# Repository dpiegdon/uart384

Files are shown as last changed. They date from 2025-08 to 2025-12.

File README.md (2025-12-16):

<!-- vim: tw=72 fo+=a
-->

UART384 - FPGA devboard & USB-stick
===================================

<div>
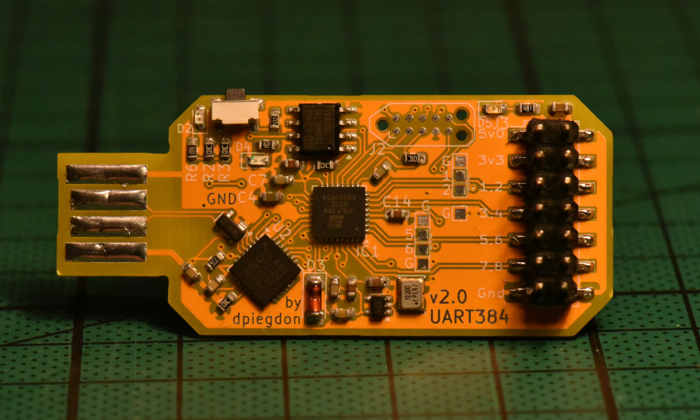
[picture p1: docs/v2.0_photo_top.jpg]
PCB-v2.0 Photo Top
    
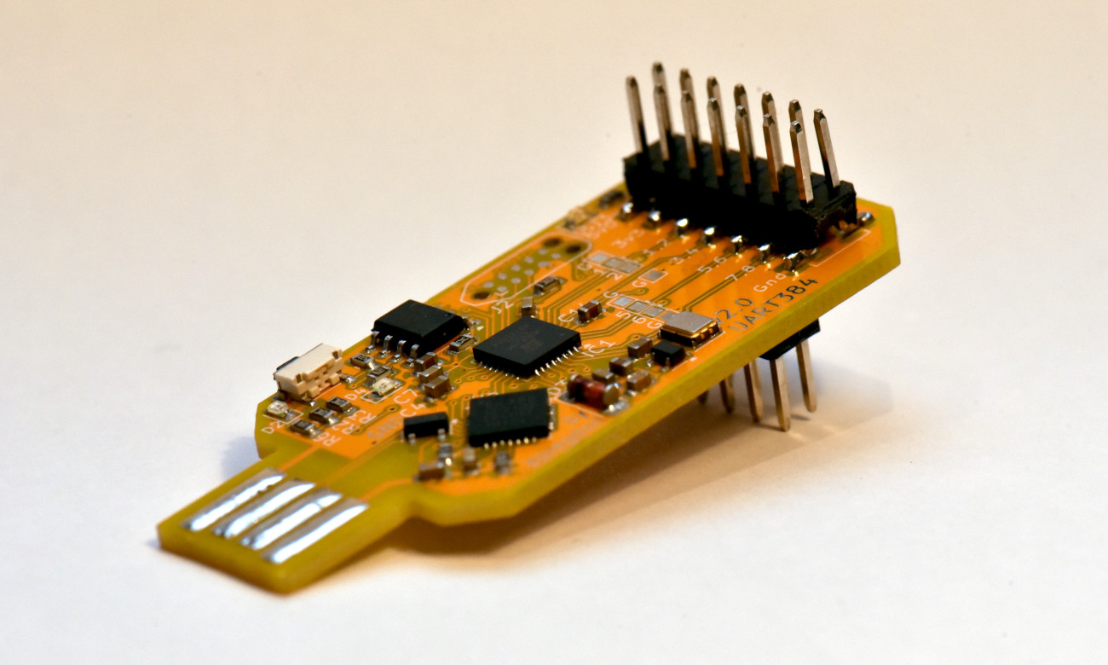
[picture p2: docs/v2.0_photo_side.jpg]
PCB-v2.0 Photo Side
    
</div>

<div>
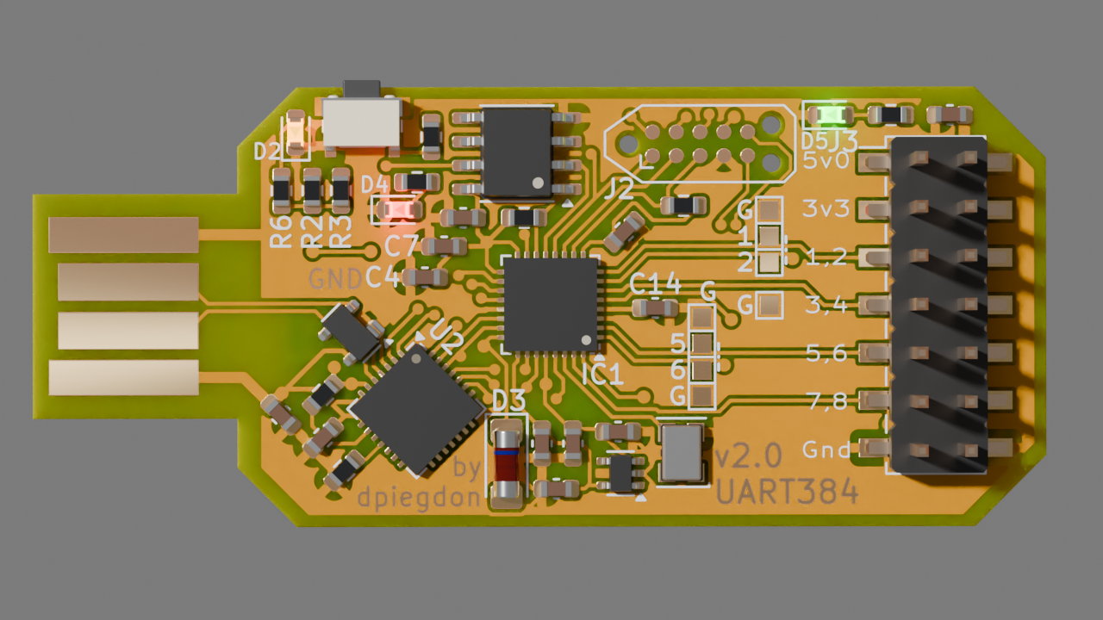
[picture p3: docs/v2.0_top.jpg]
	
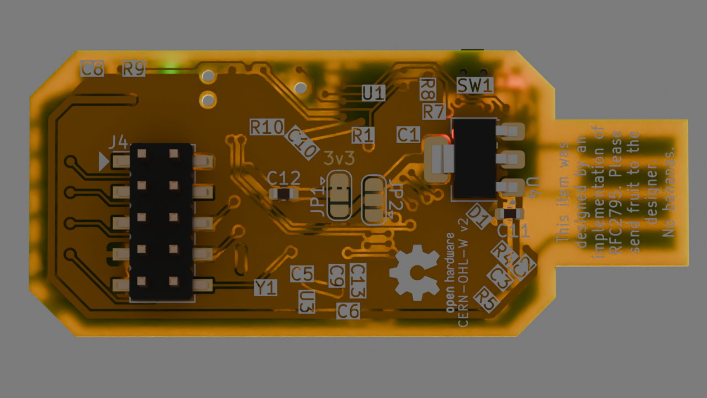
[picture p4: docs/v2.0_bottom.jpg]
	
</div>

This is a mini-devboard for the Lattice iCE40LP384, the *BEST* 🔍 FPGA
ever!

Features:
- USB-stick form-factor
- USB is connected to Silabs CP2102 USB-to-UART bridge
- Tiny Lattice iCE40LP384 with connections:
  - 384 LUTs/FFs
  - UART
  - 2 LEDs
  - 1 push-button
  - 8 GPIOs on pinheader
  - 32MHz oscillator
- small flash for bitstream
- TC2050 connector (bottom side) for programming the flash

NOTE: device is not programmable via USB

Gateware
========

"Why?", you ask?

Mostly for fun and training; there are a few gateware options available in this repository:

Entropy generator
-----------------

`gateware/entropy_generator.v`

High quality entropy source using metastability from ringoscillators fed
into the spongent hash algorithm. 

This is one of the original reasons this board was created for: I wanted
a USB stick that generates cryptographically sound entropy that can be
used to enhance system entropy on linux.

`gateware/tools/seedrng.py` can be used to receive the entropy and
inject it directly into the kernel entropy pool.

SPI and GPIO over UART tunnel
-----------------------------

`gateware/relay_spi.v`

This variant allows complex muxing of SPI lines from an SPI master core
to all GPIO1..8 pins, as well as the internal program flash. All these
pins can also be muxed as GPIO input or output and controlled/sampled.
All that via a simple UART protocol.

This gives full control of inputs and outputs, as well as efficient SPI
communication via SPI core, in any configuration. The SPI core is used
for SPI transfer by pulling RTS down, then CS is automatically pulled
down and data is seemlessly interchanged between SPI and UART.

This e.g. allows reprogramming the internal flash, or external SPI
devices, including Lattice iCE40 FPGAs if GPIOs are used to trigger
their CRESET. Since CDONE can also be sampled, this also allows
programming any iCE40 FPGA in slave mode, fully replacing any other
needed programming board to flash/program a Lattice iCE40 FPGA. Note
that the FPGA is pretty much full, no further features will be added to
this gateware.

See `gateware/tools/spi_device.py` for general SPI command abstraction,
and `gateware/tools/flashtool.py` and `gateware/tools/spi_device.py` as
an example client to work with the onboard (or any other) serial flash.

Ring oscillator entropy generator
---------------------------------

`gateware/ring_noise.v`

Low quality entropy generator using metastability from ringoscillators
fed into a linear feedback shift register.

UART pass-through
-----------------

`gateware/uart_passthrough.v`

A simple example that only passes UART signals along to the GPIO header
and shows changes on RX/TX lines on the LEDs (with some timeout).

Variable delay ring oscillator
------------------------------

`gateware/variable_ringoscillator.v`

Experiments with a ringoscillator with a reconfigurable delay-line.
Delay can be changed at runtime via UART.

License
=======

The hardware (Schematic, PCB) is licensed under CERN-OHL-W v2.
See `cern_ohl_w_v2.txt`.

The software is licensed under LGPL v2.0, unless specified otherwise
in a subrepository. See `LGPLv2.0.txt`.

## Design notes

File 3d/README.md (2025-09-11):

Tested with FreeCAD 1.0.2 and Blender 4.5.2 LTS:

FreeCAD workflow
================

Direct export of 3d STEP file
-----------------------------

In KiCad PCB Editor: File -> Export -> Step, then enable everything on the left:

- Board body
- cut vias in board body
- export silkscreen
- export solder mask
- export *all* components
- export tracks and vias
- export pads
- export zones
- export inner conductor layers
- fuse shapes
- fill all vias
- optionally on the right: ignore DNP components
- Export, saving as STEP file

In FreeCAD: import STEP file via File -> Import.

=> Now create enclosure (or whatever else) in CAD.

Old version
-----------

NOTE: this does not work well when exporting to blender at a later stage. Better use the direct 3d export above.

In KiCad PCB Editor:

- Plot silkscreen layers to DXF format:
  - File -> Plot
  - Set Plot format to DXF,
  - Select Silkscreen layers (don't care about others)
  - Plot

In FreeCAD: Use KiCadStepUp bench to:
- load board
- add tracks
- add silkscreen (exported DXF file)

Blender workflow
================

Export Enclosure and PCB
------------------------

In FreeCAD: select PCB and enclosure bodies, then: File -> Export, then export as glTF.

Import in Blender
-----------------

Import glTF file via: File -> Import.

Knock yourself out!

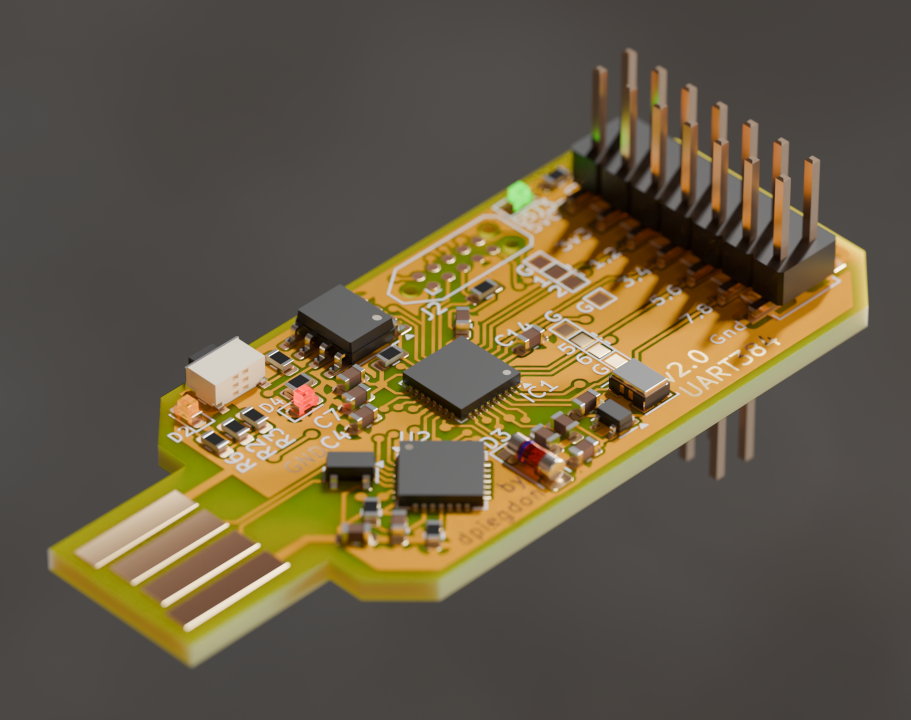
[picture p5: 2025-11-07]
docs/v2.0_side.jpg

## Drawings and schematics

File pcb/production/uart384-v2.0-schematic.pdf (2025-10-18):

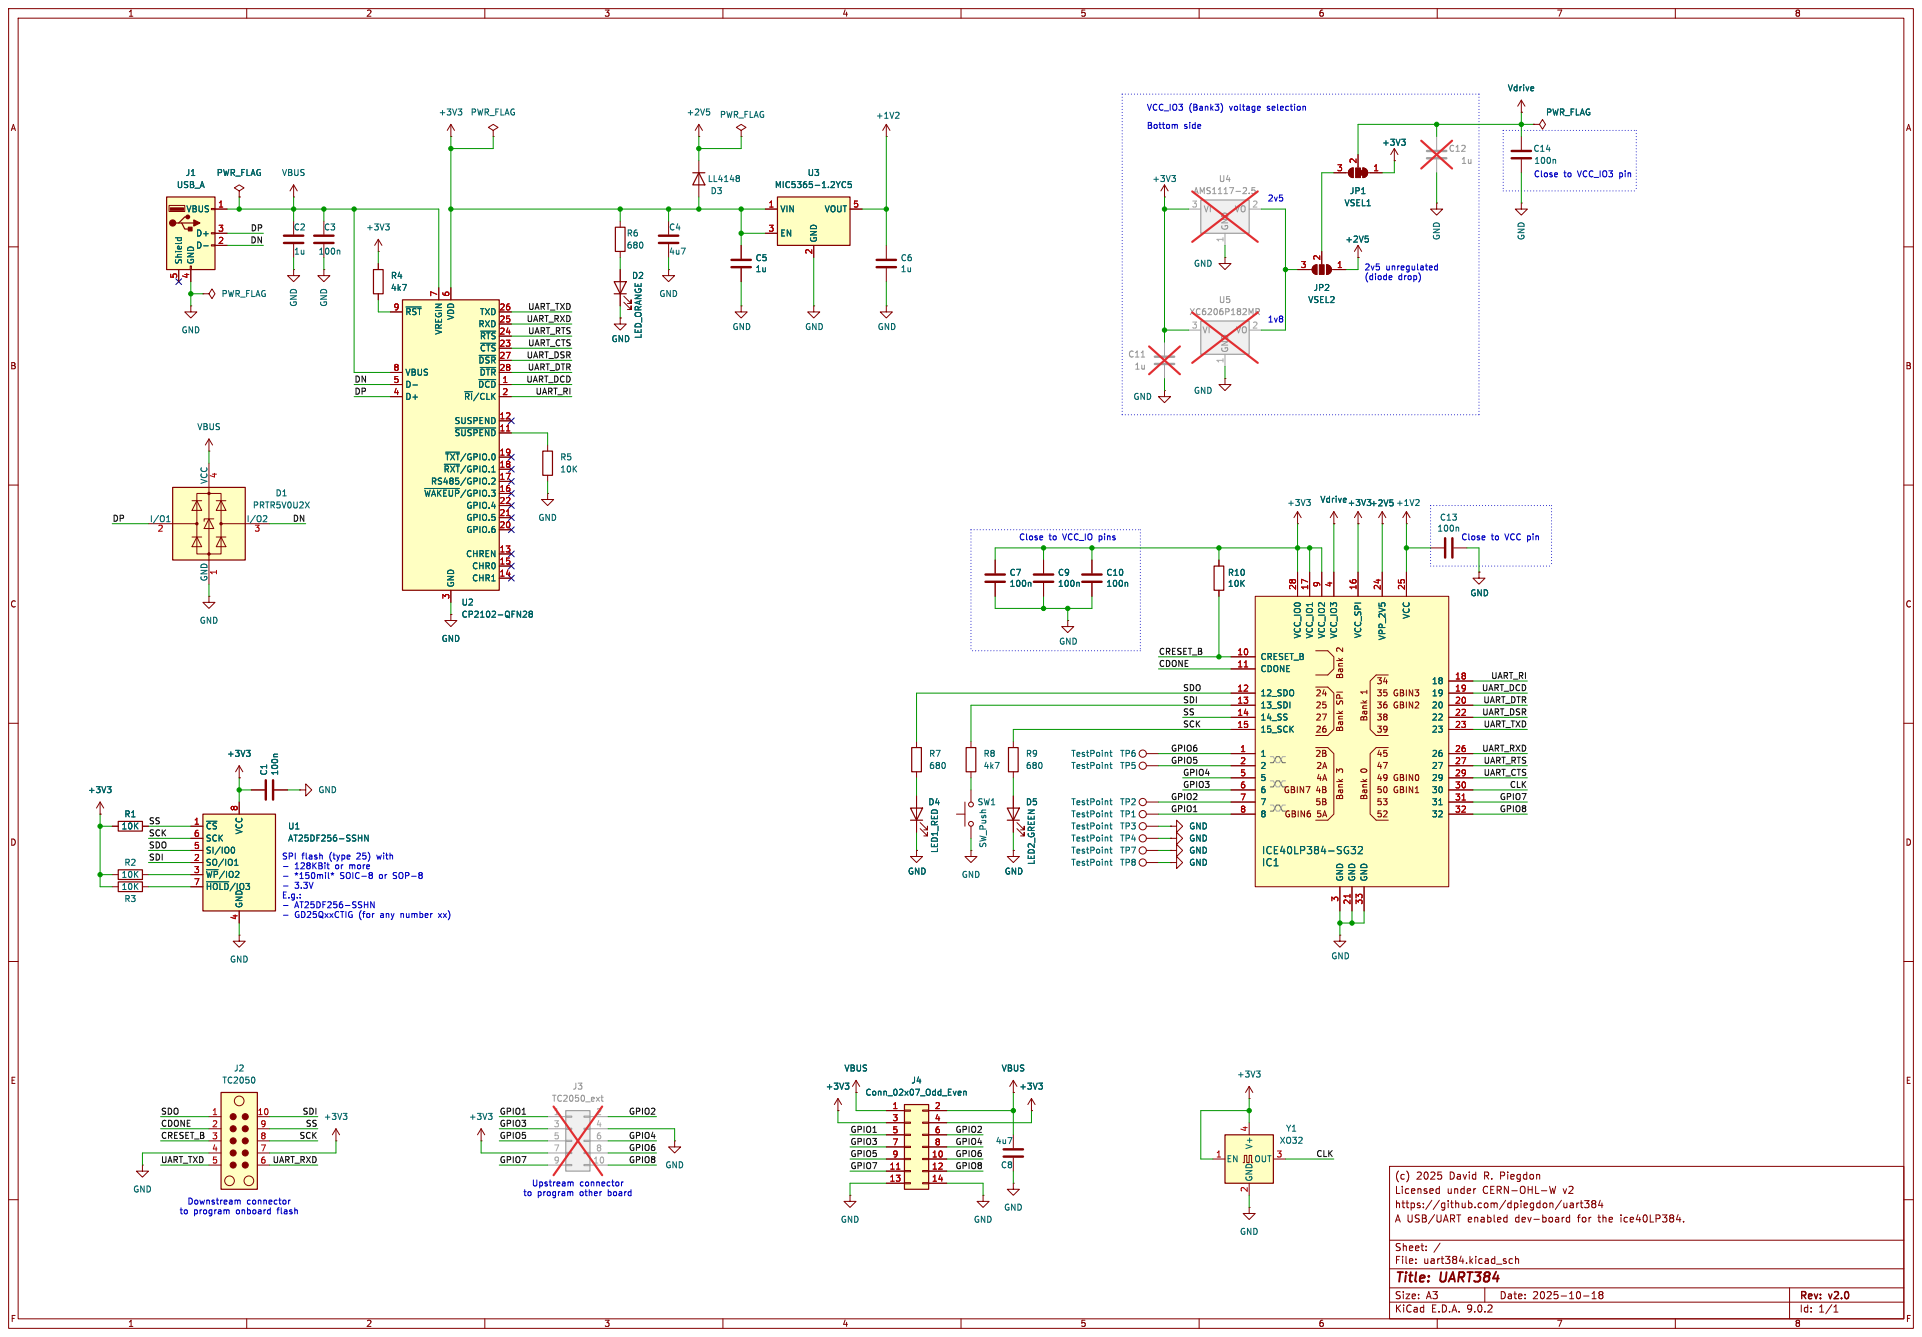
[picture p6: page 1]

(diode drop) 2v5 VCC_IO3 (Bank3) voltage selection Close to VCC_IO pins SPI flash (type 25) with

3 TXD 26 RXD 25 ~{RTS} 24 ~{CTS} 23 ~{DSR} 27 ~{DTR} 28 ~{DCD}1 ~{RI}/CLK2 SUSPEND 12 ~{SUSPEND}11 ~{TXT}/GPIO.019 ~{RXT}/GPIO.118 RS485/GPIO.2 17 ~{WAKEUP}/GPIO.316 GPIO.4 22 GPIO.5 21 GPIO.6 20 CHREN 13 CHR0 15 CHR1 14 U2 CP2102-QFN28 R4

3 TXD 26 RXD 25 ~{RTS} 24 ~{CTS} 23 ~{DSR} 27 ~{DTR} 28 ~{DCD}1 ~{RI}/CLK2 SUSPEND 12 ~{SUSPEND}11 ~{TXT}/GPIO.019 ~{RXT}/GPIO.118 RS485/GPIO.2 17 ~{WAKEUP}/GPIO.316 GPIO.4 22 GPIO.5 21 GPIO.6 20 CHREN 13 CHR0 15 CHR1 14 R4

- GD25QxxCTIG (for any number xx)

to program onboard flash

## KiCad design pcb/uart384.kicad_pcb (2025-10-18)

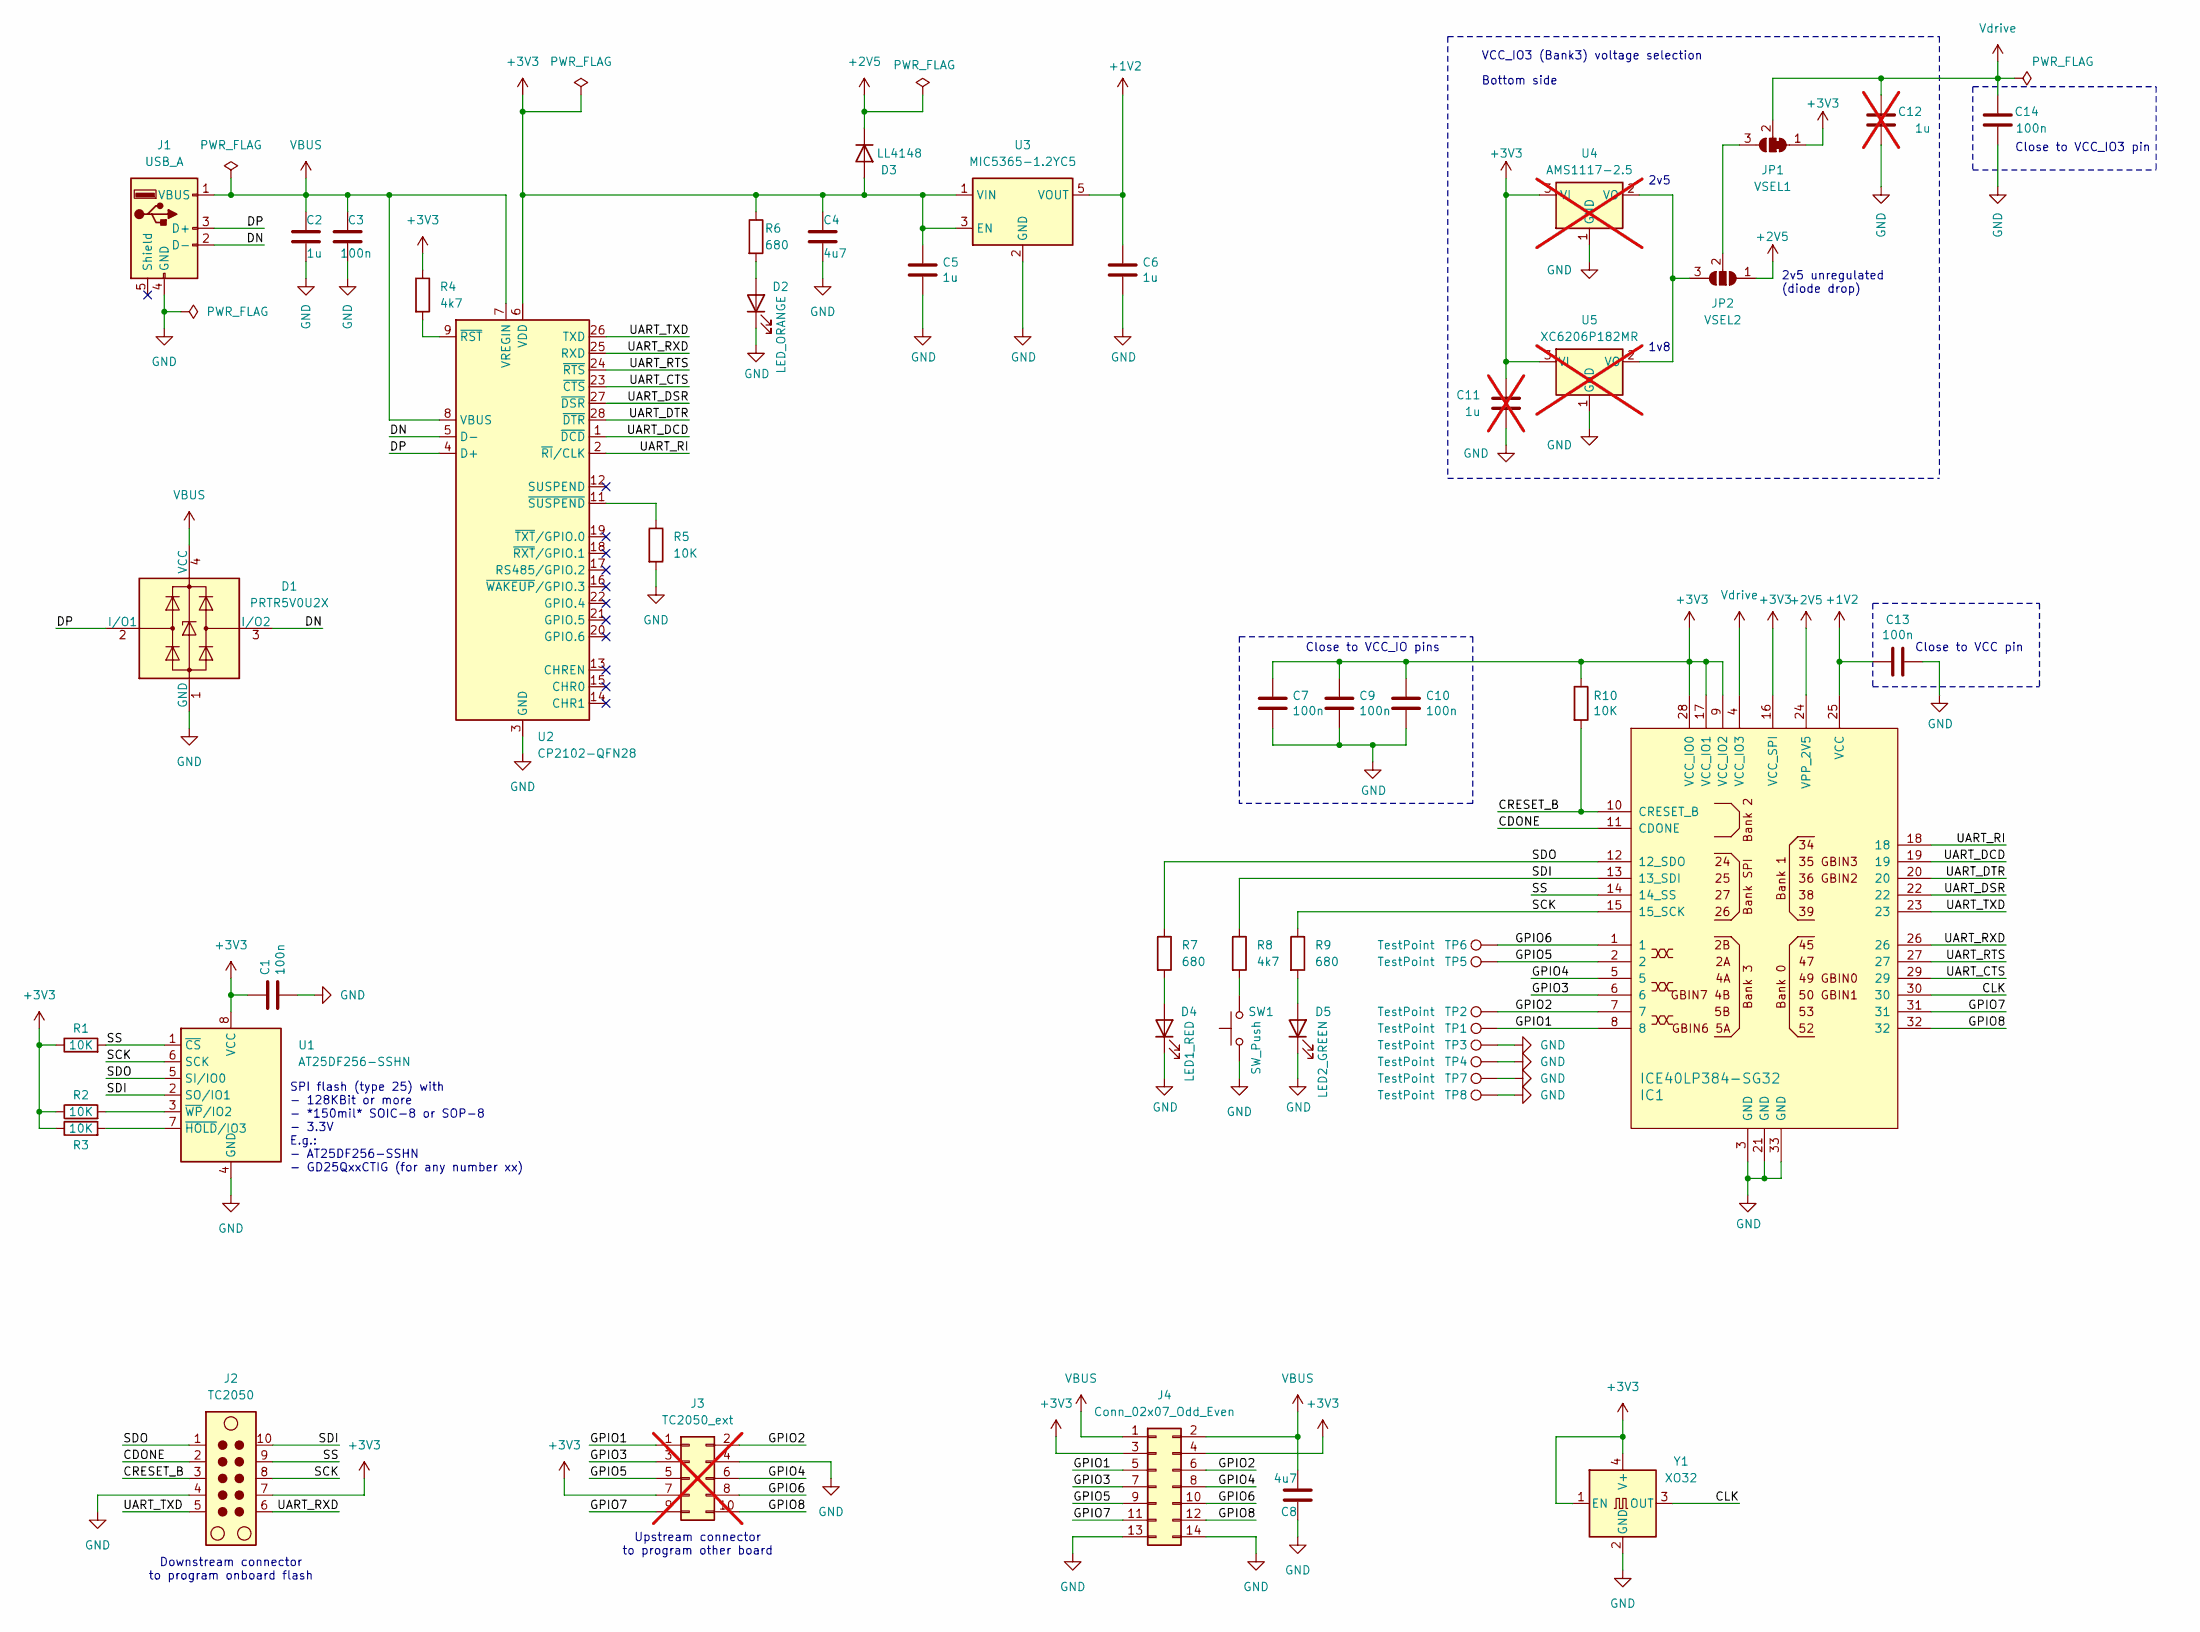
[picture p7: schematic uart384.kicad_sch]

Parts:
C1, C3, C7, C9, C10, C13, C14: 100n; C_0603_1608Metric
C2, C5, C6: 1u; C_0603_1608Metric
C4, C8: 4u7; C_0603_1608Metric
C11, C12: 1u; C_0603_1608Metric; not fitted
D1: PRTR5V0U2X; SOT-143
D2: LED_ORANGE; LED_0603_1608Metric
D3: LL4148; D_MiniMELF
D4: LED1_RED; LED_0603_1608Metric
D5: LED2_GREEN; LED_0603_1608Metric
IC1: ICE40LP384-SG32; QFN-32-1EP_5x5mm_P0.5mm_EP3.6x3.6mm
J1: USB_A; CONN-USB-A-PCB-TRACES
J2: TC2050; Tag-Connect_TC2050-IDC-NL_2x05_P1.27mm_Vertical
J3: TC2050_ext; PinHeader_2x05_P2.54mm_Vertical_SMD; not fitted
J4: Conn_02x07_Odd_Even; PinHeader_2x07_P2.54mm_Vertical_SMD
JP1: VSEL1; SolderJumper-3_P1.3mm_Bridged2Bar12_RoundedPad1.0x1.5mm
JP2: VSEL2; SolderJumper-3_P1.3mm_Open_RoundedPad1.0x1.5mm
R1, R2, R3, R5, R10: 10K; R_0603_1608Metric
R4, R8: 4k7; R_0603_1608Metric
R6, R7, R9: 680; R_0603_1608Metric
SW1: SW_Push; TS-1224W_Side_Button_2x4x3.3mm_3.5mm_3.8mm_SMD_Aliexpress
TP1, TP2, TP3, TP4, TP5, TP6, TP7, TP8: TestPoint; TestPoint_Pad_1.0x1.0mm
U1: AT25DF256-SSHN; SOIC-8_3.9x4.9mm_P1.27mm
U2: CP2102-QFN28; QFN-28-1EP_5x5mm_P0.5mm_EP3.35x3.35mm
U3: MIC5365-1.2YC5; SOT-353_SC-70-5
U4: AMS1117-2.5; SOT-223-3_TabPin2; not fitted
U5: XC6206P182MR; SOT-23-3; not fitted
Y1: XO32; Oscillator_SMD_EuroQuartz_XO32-4Pin_3.2x2.5mm

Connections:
+1V2: C6.1, C13.2, IC1.25 (VCC), U3.5 (VOUT)
+2V5: D3.1 (K), IC1.24 (VPP_2V5), JP2.1 (A)
+3V3: C1.1, C4.1, C5.1, C7.1, C9.1, C10.1, C11.2, D3.2 (A), IC1.9 (VCC_IO2), IC1.16 (VCC_SPI), IC1.17 (VCC_IO1), IC1.28 (VCC_IO0), J2.7, J3.7, J4.3, J4.4, JP1.1 (A), R1.1, R2.1, R3.1, R4.1, R6.1, R10.1, U1.8 (VCC), U2.6 (VDD), U3.1 (VIN), U3.3 (EN), U4.3 (VI), U5.3 (VI), Y1.1 (EN), Y1.4 (V+)
/CDONE: IC1.11 (CDONE), J2.2
/CLK: IC1.30, Y1.3 (OUT)
/CRESET_B: IC1.10 (CRESET_B), J2.3, R10.2
/DN: D1.3 (I/O2), J1.2 (D-), U2.5 (D-)
/DP: D1.2 (I/O1), J1.3 (D+), U2.4 (D+)
/GPIO1: IC1.8, J3.1, J4.5, TP1.1
/GPIO2: IC1.7, J3.2, J4.6, TP2.1
/GPIO3: IC1.6, J3.3, J4.7
/GPIO4: IC1.5, J3.6, J4.8
/GPIO5: IC1.2, J3.5, J4.9, TP5.1
/GPIO6: IC1.1, J3.8, J4.10, TP6.1
/GPIO7: IC1.31, J3.9, J4.11
/GPIO8: IC1.32, J3.10, J4.12
/SCK: IC1.15 (15_SCK), J2.8, R9.1, U1.6 (SCK)
/SDI: IC1.13 (13_SDI), J2.10, R8.1, U1.2 (SO/IO1)
/SDO: IC1.12 (12_SDO), J2.1, R7.1, U1.5 (SI/IO0)
/SS: IC1.14 (14_SS), J2.9, R1.2, U1.1 (~CS)
/UART_CTS: IC1.29, U2.23 (~CTS)
/UART_DCD: IC1.19, U2.1 (~DCD)
/UART_DSR: IC1.22, U2.27 (~DSR)
/UART_DTR: IC1.20, U2.28 (~DTR)
/UART_RI: IC1.18, U2.2 (~RI/CLK)
/UART_RTS: IC1.27, U2.24 (~RTS)
/UART_RXD: IC1.26, J2.6, U2.25 (RXD)
/UART_TXD: IC1.23, J2.5, U2.26 (TXD)
GND: C1.2, C2.2, C3.2, C4.2, C5.2, C6.2, C7.2, C8.1, C9.2, C10.2, C11.1, C12.1, C13.1, C14.1, D1.1 (GND), D2.1 (K), D4.1 (K), D5.1 (K), IC1.3 (GND), IC1.21 (GND), IC1.33 (GND), J1.4 (GND), J2.4, J3.4, J4.13, J4.14, R5.2, SW1.1, TP3.1, TP4.1, TP7.1, TP8.1, U1.4 (GND), U2.3 (GND), U2.29 (GND), U3.2 (GND), U4.1 (GND), U5.1 (GND), Y1.2 (GND)
unnamed: D2.2 (A), R6.2
unnamed: D4.2 (A), R7.2
unnamed: D5.2 (A), R9.2
unnamed: JP1.3 (B), JP2.2 (C)
unnamed: JP2.3 (B), U4.2 (VO), U5.2 (VO)
unnamed: R8.2, SW1.2
unnamed: R3.2, U1.7 (~HOLD/IO3)
unnamed: R2.2, U1.3 (~WP/IO2)
unnamed: R4.2, U2.9 (~RST)
unnamed: R5.1, U2.11 (~SUSPEND)
VBUS: C2.1, C3.1, C8.2, D1.4 (VCC), J1.1 (VBUS), J4.1, J4.2, U2.7 (VREGIN), U2.8 (VBUS)
Vdrive: C12.2, C14.2, IC1.4 (VCC_IO3), JP1.2 (C)

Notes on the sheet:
Upstream connector to program other board
VCC_IO3 (Bank3) voltage selection
2v5 unregulated (diode drop)
SPI flash (type 25) with - 128KBit or more - *150mil* SOIC-8 or SOP-8 - 3.3V E.g.: - AT25DF256-SSHN - GD25QxxCTIG (for any number xx)
Bottom side
2v5
1v8
Close to VCC pin
Downstream connector to program onboard flash
Close to VCC_IO pins
Close to VCC_IO3 pin

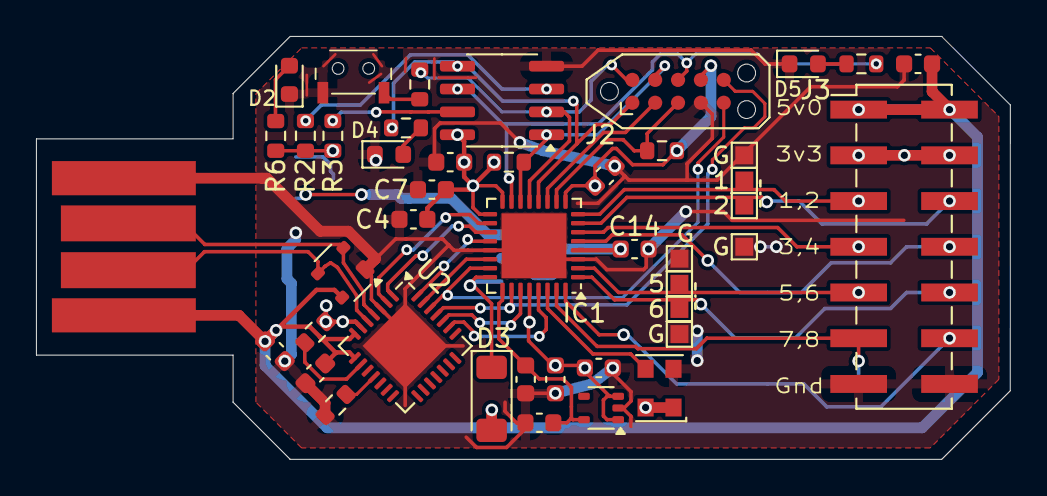
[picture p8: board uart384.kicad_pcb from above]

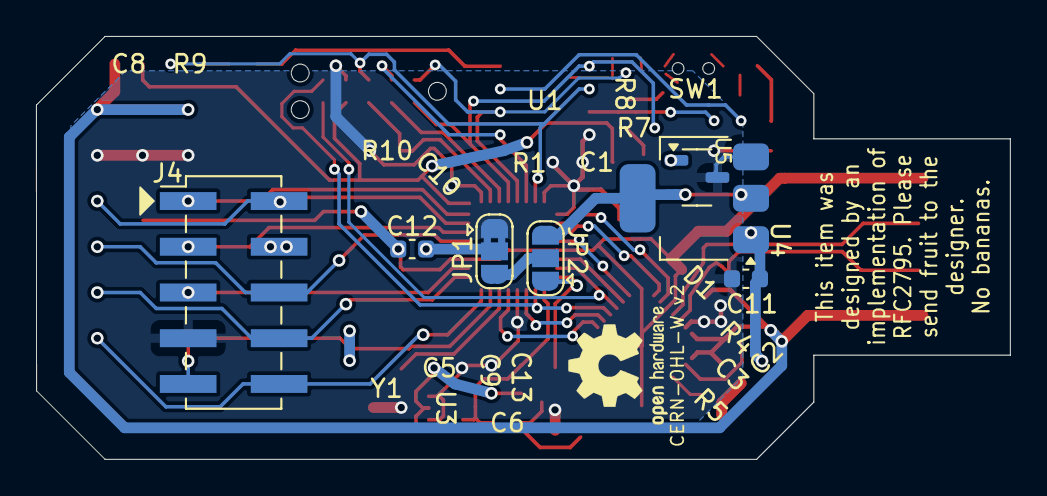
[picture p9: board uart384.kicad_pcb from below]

Board: 2 copper layers, 54.1 x 23.5 mm, 51 parts (7 on the bottom side), 41 nets.

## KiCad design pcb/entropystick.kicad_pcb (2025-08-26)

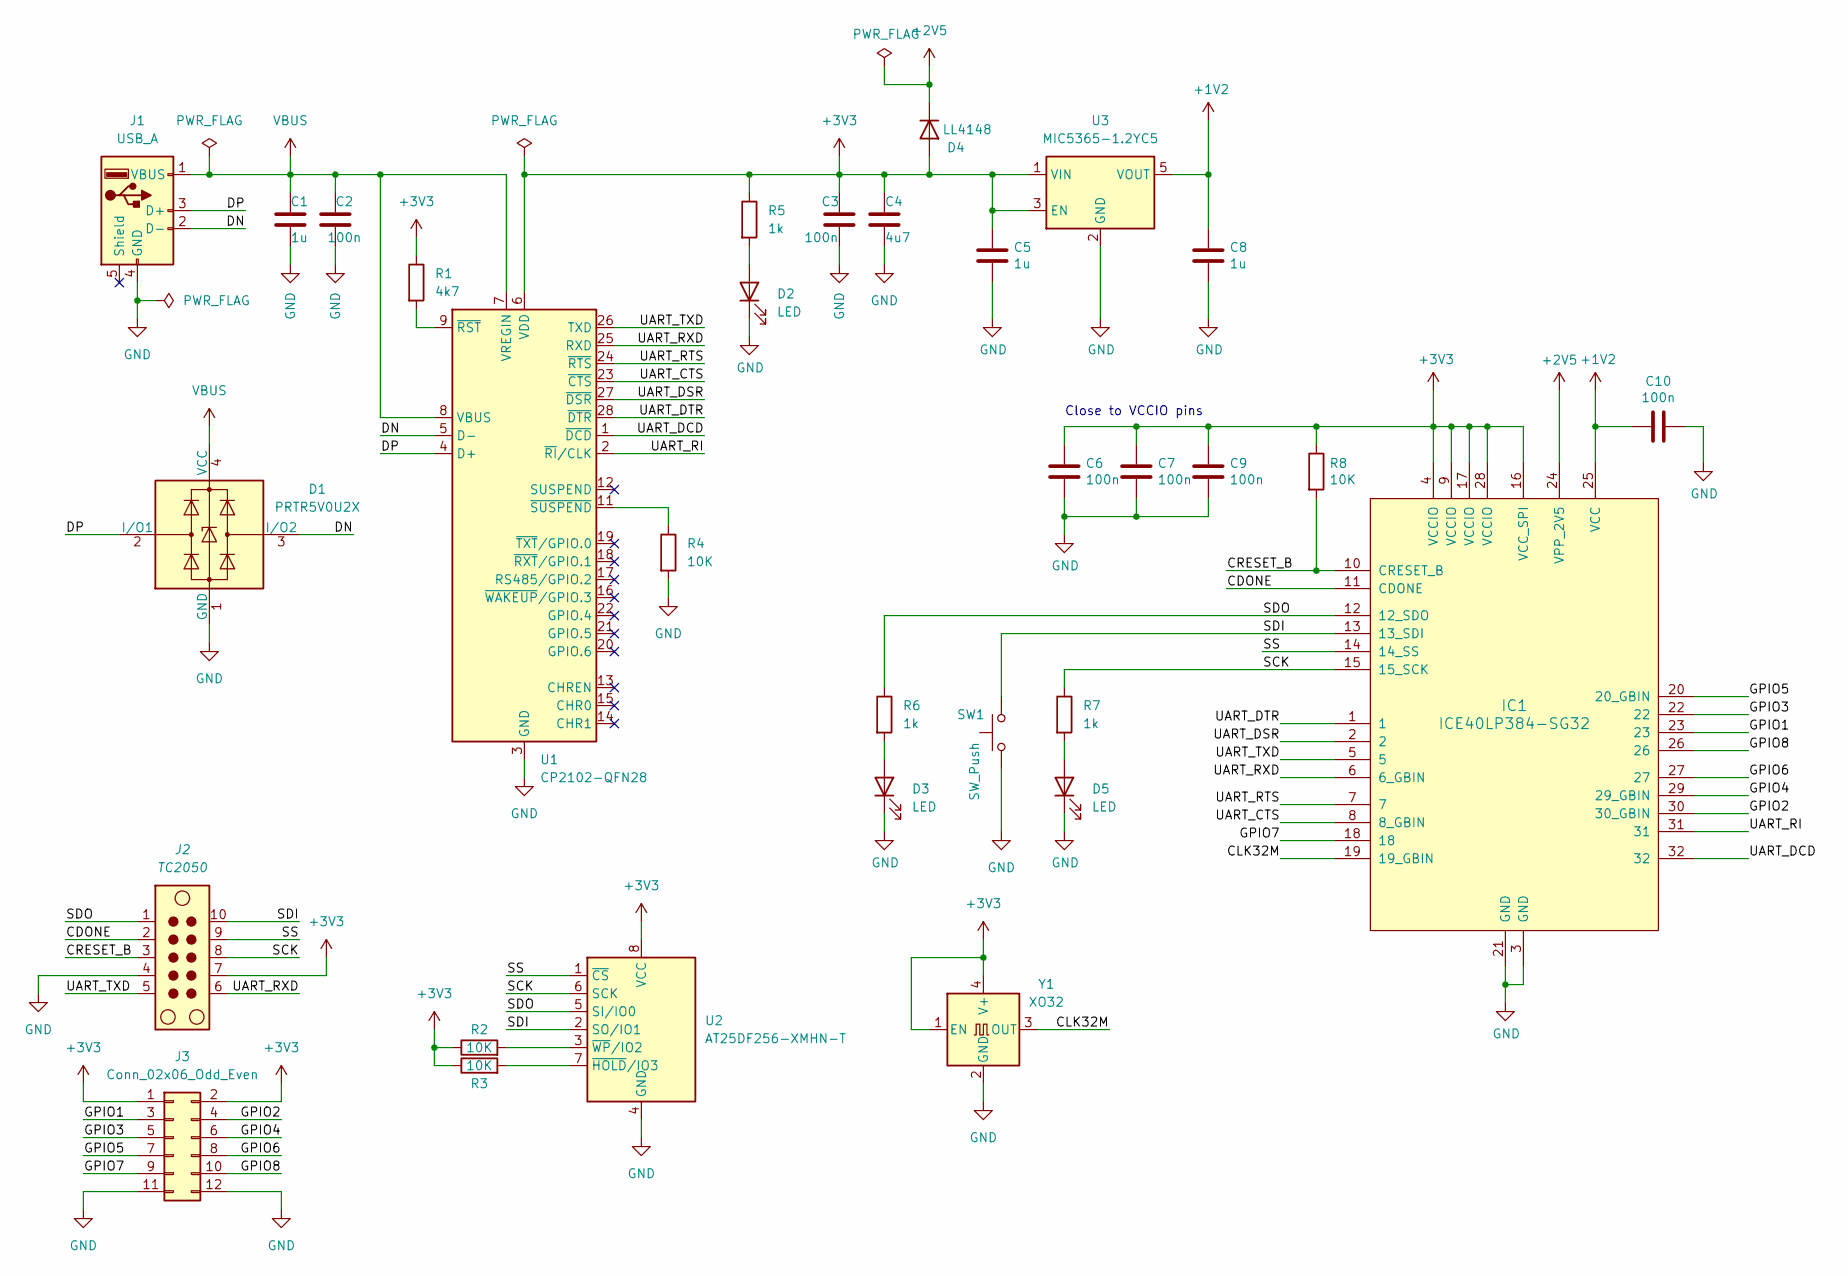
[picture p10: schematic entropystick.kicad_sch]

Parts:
C1, C5, C8: 1u; C_0603_1608Metric
C2, C3, C6, C7, C9, C10: 100n; C_0603_1608Metric
C4: 4u7; C_0603_1608Metric
D1: PRTR5V0U2X; SOT-143
D2, D3, D5: LED; LED_0603_1608Metric
D4: LL4148; D_MiniMELF
IC1: ICE40LP384-SG32; QFN-32-1EP_5x5mm_P0.5mm_EP3.6x3.6mm
J1: USB_A; CONN-USB-A-PCB-TRACES
J2: TC2050; Tag-Connect_TC2050-IDC-NL_2x05_P1.27mm_Vertical
J3: Conn_02x06_Odd_Even; PinHeader_2x06_P2.54mm_Vertical
R1: 4k7; R_0603_1608Metric
R2, R3, R4, R8: 10K; R_0603_1608Metric
R5, R6, R7: 1k; R_0603_1608Metric
SW1: SW_Push; TS-1224W_Side_Button_2x4x3.3mm_3.5mm_3.8mm_SMD_Aliexpress
U1: CP2102-QFN28; QFN-28-1EP_5x5mm_P0.5mm_EP3.35x3.35mm
U2: AT25DF256-XMHN-T; SOIC-8_3.9x4.9mm_P1.27mm
U3: MIC5365-1.2YC5; SOT-353_SC-70-5
Y1: XO32; Oscillator_SMD_EuroQuartz_XO32-4Pin_3.2x2.5mm

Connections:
+1V2: C8.1, C10.2, IC1.25 (VCC), U3.5 (VOUT)
+2V5: D4.1 (K), IC1.24 (VPP_2V5)
+3V3: C3.1, C4.1, C5.1, C6.1, C7.1, C9.1, D4.2 (A), IC1.4 (VCCIO), IC1.9 (VCCIO), IC1.16 (VCC_SPI), IC1.17 (VCCIO), IC1.28 (VCCIO), J2.7, J3.1, J3.2, R1.1, R2.1, R3.1, R5.1, R8.1, U1.6 (VDD), U2.8 (VCC), U3.1 (VIN), U3.3 (EN), Y1.1 (EN), Y1.4 (V+)
/CDONE: IC1.11 (CDONE), J2.2
/CLK32M: IC1.19 (19_GBIN), Y1.3 (OUT)
/CRESET_B: IC1.10 (CRESET_B), J2.3, R8.2
/DN: D1.3 (I/O2), J1.2 (D-), U1.5 (D-)
/DP: D1.2 (I/O1), J1.3 (D+), U1.4 (D+)
/GPIO1: IC1.23, J3.3
/GPIO2: IC1.30 (30_GBIN), J3.4
/GPIO3: IC1.22, J3.5
/GPIO4: IC1.29 (29_GBIN), J3.6
/GPIO5: IC1.20 (20_GBIN), J3.7
/GPIO6: IC1.27, J3.8
/GPIO7: IC1.18, J3.9
/GPIO8: IC1.26, J3.10
/SCK: IC1.15 (15_SCK), J2.8, R7.1, U2.6 (SCK)
/SDI: IC1.13 (13_SDI), J2.10, SW1.2, U2.2 (SO/IO1)
/SDO: IC1.12 (12_SDO), J2.1, R6.1, U2.5 (SI/IO0)
/SS: IC1.14 (14_SS), J2.9, U2.1 (~CS)
/UART_CTS: IC1.8 (8_GBIN), U1.23 (~CTS)
/UART_DCD: IC1.32, U1.1 (~DCD)
/UART_DSR: IC1.2, U1.27 (~DSR)
/UART_DTR: IC1.1, U1.28 (~DTR)
/UART_RI: IC1.31, U1.2 (~RI/CLK)
/UART_RTS: IC1.7, U1.24 (~RTS)
/UART_RXD: IC1.6 (6_GBIN), J2.6, U1.25 (RXD)
/UART_TXD: IC1.5, J2.5, U1.26 (TXD)
GND: C1.2, C2.2, C3.2, C4.2, C5.2, C6.2, C7.2, C8.2, C9.2, C10.1, D1.1 (GND), D2.1 (K), D3.1 (K), D5.1 (K), IC1.3 (GND), IC1.21 (GND), J1.4 (GND), J2.4, J3.11, J3.12, R4.2, SW1.1, U1.3 (GND), U1.29 (GND), U2.4 (GND), U3.2 (GND), Y1.2 (GND)
unnamed: D2.2 (A), R5.2
unnamed: D3.2 (A), R6.2
unnamed: D5.2 (A), R7.2
unnamed: R1.2, U1.9 (~RST)
unnamed: R4.1, U1.11 (~SUSPEND)
unnamed: R3.2, U2.7 (~HOLD/IO3)
unnamed: R2.2, U2.3 (~WP/IO2)
VBUS: C1.1, C2.1, D1.4 (VCC), J1.1 (VBUS), U1.7 (VREGIN), U1.8 (VBUS)

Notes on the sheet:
Close to VCCIO pins

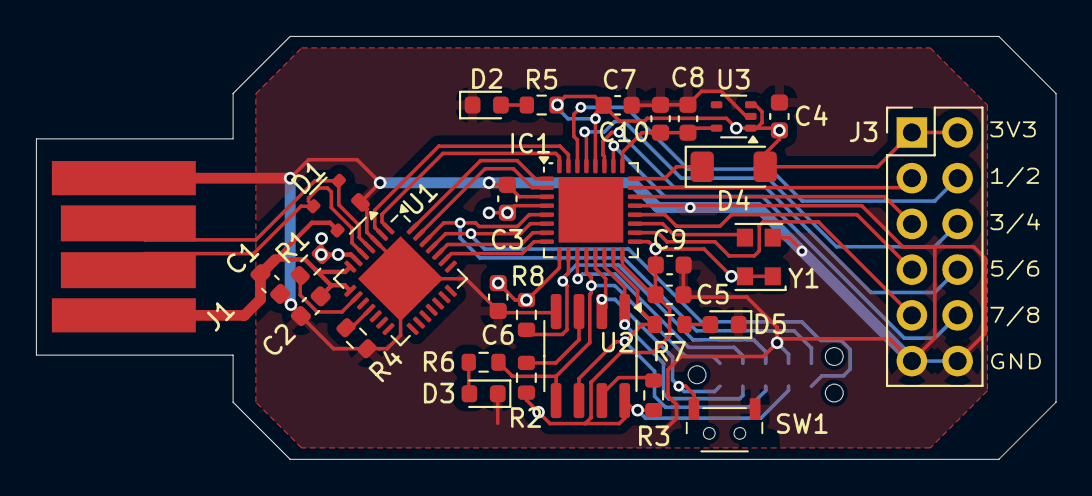
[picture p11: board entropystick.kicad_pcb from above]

Board: 2 copper layers, 56.6 x 23.5 mm, 32 parts (1 on the bottom side), 37 nets.

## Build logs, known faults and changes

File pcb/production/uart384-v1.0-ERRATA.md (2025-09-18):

v1.0 PCB Errata
===============

#1: Wrong SPI flash footprint
-----------------------------

[x] Fixed in main branch / v1.1~

Footprint for SPI flash (SOIC-8 150mil) mismatches partnumber AT25DF256-XMHN-T (TSSOP).

Valid replacement parts for SOIC-8 150mil footprint:

SPI flash (type 25) with

- 128KBit or more
- *150mil* SOIC-8 or SOP-8
- 3.3V

E.g.:

- AT25DF256-SSHN
- GD25QxxCTIG (for any number xx)

#2: SPI SS pullup missing
-------------------------

[x] Fixed in main branch / v1.1~

For some flash memory and some electrical circumstances the flash will need a pullup on the SS lines,
otherwise programming of the first bytes of every page can fail, resulting in the FPGA refusing the stored the bitstream.

Fix: add a 10K pull-up as can e.g. be seen in the ICEstick schematic.

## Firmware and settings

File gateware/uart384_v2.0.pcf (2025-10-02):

# This file is part of the UART384 software & gateware
# (c) 2025 by David R. Piegdon <dgit@piegdon.de>
#
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
# uart384 hardware v2.0

# UART port
set_io --warn-no-port uart_dtr 20
set_io --warn-no-port uart_dsr 22
set_io --warn-no-port uart_txd 23
set_io --warn-no-port uart_rxd 26
set_io --warn-no-port uart_rts 27
set_io --warn-no-port uart_cts 29
set_io --warn-no-port uart_ri  18
set_io --warn-no-port uart_dcd 19

# clock
set_io --warn-no-port clk      30

# GPIO port
set_io --warn-no-port gpio1    8
set_io --warn-no-port gpio2    7
set_io --warn-no-port gpio3    6
set_io --warn-no-port gpio4    5
set_io --warn-no-port gpio5    2
set_io --warn-no-port gpio6    1
set_io --warn-no-port gpio7    31
set_io --warn-no-port gpio8    32

# program-flash SPI with multiplexed functions.
# use additional functions only when SPI_SS is HIGH.
set_io --warn-no-port SPI_SDO_led1_red   12
set_io --warn-no-port SPI_SDI_button     13
set_io --warn-no-port SPI_SS             14
set_io --warn-no-port SPI_SCK_led2_green 15

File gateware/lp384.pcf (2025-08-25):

set_io --warn-no-port uart_dtr 1
set_io --warn-no-port uart_dsr 2
set_io --warn-no-port uart_txd 5
set_io --warn-no-port uart_rxd 6
set_io --warn-no-port uart_rts 7
set_io --warn-no-port uart_cts 8
set_io --warn-no-port uart_ri  31
set_io --warn-no-port uart_dcd 32

set_io --warn-no-port clk32m   19

set_io --warn-no-port gpio1    23
set_io --warn-no-port gpio2    30
set_io --warn-no-port gpio3    22
set_io --warn-no-port gpio4    29
set_io --warn-no-port gpio5    20
set_io --warn-no-port gpio6    27
set_io --warn-no-port gpio7    18
set_io --warn-no-port gpio8    26

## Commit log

2025-08-24 initial draft concept
    [entropystick.kicad_pcb, entropystick.kicad_sch]
2025-08-25 improve pin assignments, place&route
    [entropystick.kicad_pcb, entropystick.kicad_sch]
2025-08-26 improve PCB
    [entropystick.kicad_pcb, entropystick.kicad_sch]
2025-08-26 add switch, LED; verify USB connector dimensions
    [entropystick.kicad_pcb, entropystick.kicad_sch]
2025-08-26 rename to uart384, since hardware is generic
    [uart384.kicad_pcb, uart384.kicad_sch]
2025-08-26 setup 3d models, PCB color; create rendering; improve docs
    [uart384.kicad_pcb]
2025-08-26 release PCB v1.0: setup production files, docs
    [uart384.kicad_pcb, uart384.kicad_sch]
2025-09-11 use improved LP384 symbol (no functional changes)
    [uart384.kicad_pcb, uart384.kicad_sch]
2025-09-11 add uart-passthrough example, improve Makefile and docs
2025-09-11 clocktest: add uart feedback on which tap is used
2025-09-11 expose SPI port to flash, update verilog-buildingblocks.
2025-09-11 PCBv1 Errata: Mismatch between SPI flash footprint and selected part#.
    Part now must be SOIC-8 150mil / SOP-8 150mil.
    Updated part#s in schematic / PCB.
    [uart384.kicad_pcb, uart384.kicad_sch]
2025-09-16 entropy-generator: expose some internal state via LED and GPIO8
2025-09-16 synthesis: run synth_ice40 with `-abc2` to enable optimization at abc stage.
    Enabled parameters are now:
    -dff run 'abc'/'abc9' with -dff option
    -abc2 run two passes of 'abc' for slightly improved logic density
    Adding -abc2 reduces size by about 12 LUTs (328 -> 316).
2025-09-18 gateware: inverse LEDs for uart passthrough.
2025-09-18 PCBv1 Errata: SPI SS pullup missing
    [uart384.kicad_pcb, uart384.kicad_sch]
2025-09-19 name LEDs with used colors. use LEDs for more things.
    [uart384.kicad_pcb, uart384.kicad_sch]
2025-09-20 PCB: add 5V to pinheader, move switch, LED, some resistors, improve routing
    [uart384.kicad_pcb, uart384.kicad_sch]
2025-09-25 implement relay of SPI commands via UART, python script to talk to program-flash
2025-09-25 python tooling to work with SPI flash
2025-09-26 python spi bridge: add security-registers access
2025-09-26 python spi bridge: rebrand and add verification process
2025-09-27 PCB: add additional header for upstream TC2050, re-route PCB.
    Adding J4 for the "other" side of a TC2050 cable allows programming a
    UART384 with another UART384, once a gateware is written that also can
    control CDONE and CRESET lines. This enables full bootstrapping of a
    UART384 with a UART384 :-D
    [uart384.kicad_pcb, uart384.kicad_sch]
2025-09-29 PCB: add LP384 GND center pad from upstream symbol, improve schematic and routing
    [uart384.kicad_pcb, uart384.kicad_sch]
2025-09-29 add CP210x program script and `blink` gateware to test LEDs and GPIOs
2025-09-29 PCB: major hardware revision 2.0~DEV: restructure FPGA pinout, fully reroute.
    - re-map iCE40LP384 pins for GPIO 1-8, UART, CLK to optimize usability
    and allow experiments with LVDS pairs.
    - allow voltage selection for LVDS pins (bank 3) between 3v3 (default)
    and 2v5 (untested, only via diode drop!).
    - make programming pad TC2050 fully available, take care not to place
    components on other side of it.
    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
    [uart384.kicad_pcb, uart384.kicad_sch]
2025-09-30 PCB: add voltage regulator choices for VCC_IO3, selectable via jumper, DNP
    [uart384.kicad_pcb, uart384.kicad_sch]
2025-10-02 plaster everything with licenses and copyright notices.
    [uart384.kicad_pcb, uart384.kicad_sch]
2025-10-04 optimize the shit out of the PCB because I'm bored.
    [uart384.kicad_pcb, uart384.kicad_sch]
2025-10-09 PCB: add in-line resistor to switch SW1 to avoid possible shorts.
    [uart384.kicad_pcb, uart384.kicad_sch]
2025-10-09 gateware: improve relay_spi to allow complex muxing of SPI and configurable GPIO pins
2025-10-11 gateware: relay_spi: reduce and improve available mux functions
2025-10-11 gateware: relay_spi: allow read-back of mux registers before writing them
2025-10-11 gateware: relay_spi: handle reads always on address-byte
2025-10-11 gateware: relay_spi: adapt python script so that it mostly works
2025-10-12 gateware: relay_spi: let python-scripts support programming external flash via TC2050
2025-10-13 gateware: relay_spi: extend features
2025-10-13 add test-pads for easy access to differential pair GPIO1/GPIO2
    [uart384.kicad_pcb, uart384.kicad_sch]
2025-10-14 PCB: add test-pads for easy access to differential pair GPIO5/GPIO6
    [uart384.kicad_pcb, uart384.kicad_sch]
2025-10-17 gateware: use improved SPI master from buildingblocks
2025-10-17 gateware: fix syntax issues for userspace helper
    [spi_device.py]
2025-10-18 release PCB v2.0: production files, schematic
    [uart384.kicad_pcb, uart384.kicad_sch]
2025-11-07 v2 PCB renderings
2025-11-07 switch gateware to PCB v2.0
2025-11-08 relay_spi: juggle until all important registers can be read back
2025-11-08 adopt `black` python formatting rules
    black --line-length 90 --skip-string-normalization
    [flashtool.py, seedrng.py, spi_device.py]
2025-11-28 add html BOM for v2.0 PCB
2025-11-29 gateware: relay_spi: fix python-tool to work with v2.0 access to external flash
    [spi_device.py]

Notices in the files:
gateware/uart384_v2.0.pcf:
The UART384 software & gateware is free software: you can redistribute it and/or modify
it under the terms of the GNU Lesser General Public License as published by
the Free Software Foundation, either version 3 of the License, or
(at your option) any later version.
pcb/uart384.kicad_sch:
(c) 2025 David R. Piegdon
